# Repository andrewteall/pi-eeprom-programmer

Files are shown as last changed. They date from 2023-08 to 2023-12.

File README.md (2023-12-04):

# __A Raspberry Pi GPIO EEPROM Writer and Reader__ 

A way to write Parallel and Serial EEPROMs using the Raspberry Pi GPIO pins.

## __Quick Start__

### __Building the Circuit__
Before reading or writing any EEPROM you have to build the apprpriate circuit to do so.

You'll need a breadboard, jumper wires, and a 40-pin connector and cable to attach to the GPIO pins of the Raspberry Pi and a way to connect the opposite end to the breadboard. I like using one of the many Raspberry Pi GPIO Breakout boards available.

__Serial I2C EEPROM Circuit__
```
            Raspberry Pi GPIO                         I2C DIP8 Serial EEPROM
            3V3  (1) (2)  5V                   GND <-  A0 | (1) (8) | VCC -> 3V3
 SDA 5 -> GPIO2  (3) (4)  5V                   GND <-  A1 | (2) (7) | WP  -> GPIO16 (36)
 SCL 6 -> GPIO3  (5) (6)  GND                  GND <-  A2 | (3) (6) | SCL -> GPIO2  (3)
          GPIO4  (7) (8)  GPIO14               GND <- GND | (4) (5) | SDA -> GPIO3  (5)
            GND  (9) (10) GPIO15
         GPIO17 (11) (12) GPIO18
         GPIO27 (13) (14) GND   
         GPIO22 (15) (16) GPIO23
            3V3 (17) (18) GPIO24
         GPIO10 (19) (20) GND   
          GPIO9 (21) (22) GPIO25
         GPIO11 (23) (24) GPIO8 
            GND (25) (26) GPIO7 
          GPIO0 (27) (28) GPIO1 
          GPIO5 (29) (30) GND   
          GPIO6 (31) (32) GPIO12
         GPIO13 (33) (34) GND   
         GPIO19 (35) (36) GPIO16 -> 7 WP
         GPIO26 (37) (38) GPIO20
            GND (39) (40) GPIO21
   ```

   __Parallel EEPROM Circuit__
```
 IC  |   Raspberry Pi GPIO      | IC  |        Pi  |  DIP28 Parallel EEPROM  |  Pi         | DIP24 Parallel EEPROM
          3V3  (1) (2)  5V            |  (7)  GPIO4 <-  A14  (1) (28) VCC  -> 5V           |
I/O3 -> GPIO2  (3) (4)  5V            | (11) GPIO17 <-  A12  (2) (27) /WE  -> GPIO14 (8)   |
I/O4 -> GPIO3  (5) (6)  GND           | (13) GPIO27 <-   A7  (3) (26) A13  -> GPIO15 (10)  | VCC -> 5V
A14 ->  GPIO4  (7) (8)  GPIO14 -> /WE | (15) GPIO22 <-   A6  (4) (25) A8   -> GPIO18 (12)  | 
          GND  (9) (10) GPIO15 -> A13 | (19) GPIO10 <-   A5  (5) (24) A9   -> GPIO23 (16)  | 
A12 -> GPIO17 (11) (12) GPIO18 -> A8  | (21)  GPIO9 <-   A4  (6) (23) A11  -> GPIO24 (18)  | /WE -> GPIO14 (8)
 A7 -> GPIO27 (13) (14) GND           | (23) GPIO11 <-   A3  (7) (22) /OE  -> GPIO25 (22)  | 
 A6 -> GPIO22 (15) (16) GPIO23 -> A9  | (27)  GPIO0 <-   A2  (8) (21) A10  -> GPIO8  (24)  | 
          3V3 (17) (18) GPIO24 -> A11 | (29)  GPIO5 <-   A1  (9) (20) /CE  -> GPIO7  (26)  | 
 A5 -> GPIO10 (19) (20) GND           | (31)  GPIO6 <-   A0 (10) (19) I/O7 -> GPIO1  (28)  | 
 A4 ->  GPIO9 (21) (22) GPIO25 -> /OE | (33) GPIO13 <- I/O0 (11) (18) I/O6 -> GPIO12 (32)  | 
 A3 -> GPIO11 (23) (24) GPIO8  -> A10 | (35) GPIO19 <- I/O1 (12) (17) I/O5 -> GPIO16 (36)  | 
          GND (25) (26) GPIO7  -> /CE | (37) GPIO26 <- I/O2 (13) (16) I/O4 -> GPIO3  (38)  | 
 A2 ->  GPIO0 (27) (28) GPIO1  -> I/O7|          GND <- GND (14) (15) I/O3 -> GPIO2  (40)  | 
 A1 ->  GPIO5 (29) (30) GND           |
 A0 ->  GPIO6 (31) (32) GPIO12 -> I/O6| 
I/O0 ->GPIO13 (33) (34) GND           |
I/O1 ->GPIO19 (35) (36) GPIO16 -> I/O5| 
I/O2 ->GPIO26 (37) (38) GPIO20        | 
          GND (39) (40) GPIO21 ->     | 
   ```

   Alternatively a pcb can be ordered from any of the various manufacturers from the zipped gerbers contained in `hardware/manufacturing/pi-eeprom-programmer-v.v.v.zip`.

### __Installation and Raspberry Pi Setup__

If you plan to use serial EEPROMs you'll need to setup I2C on the Raspberry Pi. [Adafruit](https://learn.adafruit.com/adafruits-raspberry-pi-lesson-4-gpio-setup/configuring-i2c) has a great tutorial. Typically, if you're just using parallel EEPROM's then you can proceed to the next step. However, if the `libgpiod2` and `libgpiod-dev` packages are not installed on your Raspberry Pi you will need to to install them.

Download and compile the programmer software
```
git clone git@github.com:andrewteall/pi-eeprom-programmer.git
cd pi-eeprom-programmer/software
make
```

Install piepro

```
make install
```

That's it. You should be able to start reading and writing EEPROMs.

### __Installing the IC__
If you've recreated the circuit exactly from above or are using the pcb the IC should be installed so that the bottom left pin of the IC is aligned to the bottom left of the circuit.

### __Reading from an EEPROM__

To read an EEPROM, after building the circuit and inserting the IC, run the command
```sh
piepro -d -m EEPROM_MODEL
```
Where EEPROM_MODEL is typically the IC's part number such as at28c64, xl2816, at24c02, etc... This will dump the EEPROM's contents to standard out in a pretty format. If you wish to start or limit the addresses dumped you may specify the `-s ADDRESS` or `-l ADDRESS` flags respectively.

### __Writing to an EEPROM__

To write to an EEPROM, after building the circuit and inserting the IC, run the command
```sh
piepro -w file.bin -m EEPROM_MODEL
```
To compare you EEPROM to the file after writing, run the command

```sh
piepro -c file.bin -m EEPROM_MODEL
```
Where EEPROM_MODEL is typically the IC's part number such as at28c64, xl2816, at24c02, etc...

#### __A Quick Note About EEPROM Voltages__
Most modern EERPOMs will work but if you're using an obscure EEPROM you need to makes sure it can operate on 5v Vcc and 3.3v levels if it's a parallel EEPROM and 3.3v Vcc and 3.3v levels if it's a serial EEPROM.

## __Command Line Options__
```
Usage: piepro [options]
Options:
 -c FILE,   --compare FILE  Compare FILE and EEPROM and print number of differences.
            --chipname      Specify the chipname to use. Default: gpiochip0
 -d [N],    --dump [N]      Dump the contents of the EEPROM, 
                            0=PRETTY_WITH_ASCII, 1=BINARY, 2=TEXT, 3=LABELED, 4=PRETTY. Default: PRETTY_WITH_ASCII
 -e [N],    --erase [N]     Erase eeprom with specified byte. Default: 0xFF
 -f,        --force         Force writing of every byte instead of checking for existing value first.
 -id,       --i2c-device-id The address id of the I2C device.
 -h,        --help          Print this message and exit.
 -l N,      --limit N       Specify the maximum address to operate.
 -m MODEL,  --model MODEL   Specify EERPOM device model. Default: AT28C16.
            --no-validate-write 
                            Do not perform a read directly after writing to verify the data was written.
 -r [N],    --read [N]      Read the contents of the EEPROM, 
                            0=PRETTY_WITH_ASCII, 1=BINARY, 2=TEXT, 3=LABELED, 4=PRETTY. Default: PRETTY_WITH_ASCII
 -rb N,     --read-byte ADDRESS 
                            Read From specified ADDRESS.
 -q [N],     --quick [N]    Operates on N bytes at once for reads. Page Size if unspecified or writes. 
                            Implied --force and --no-validate-write.
 -s N,      --start N       Specify the minimum address to operate.
 -t,        --text          Interpret file as a text. Default: binary
                            Text File format:
                            [00000000]00000000 00000000
 -v N,      --v[vvvv]       Set the log verbosity to N, 0=OFF, 1=FATAL, 2=ERROR, 3=WARNING, 4=INFO, 5=DEBUG 6=TRACE. Default: WARNING
            --version       Print the piepro version and exit.
 -w FILE,   --write FILE    Write EEPROM with specified file.
 -wb ADDRESS DATA, --write-byte ADDRESS DATA 
                            Write specified DATA to ADDRESS.
 -wd [N],   --write-delay N Enable write delay. N Number of microseconds to delay between writes.
 -y,        --yes           Automatically answer Yes to write or erase EEPROM.

 Supported and tested Models:
        Note that the program may work if your EEPROM uses a similar pinout and
        voltages to the ones listed.
 Model       Size(B)  Addr Len  Data Len   Write Cycle(uS)  Page Size(B) Address Size(B)
----------------------------------------------------------------------------------------
xl2816        2048       11         8          10000            16             0
xl28c16       2048       11         8          10000            16             0
at28c16       2048       11         8           5000            16             0
at28c64       8192       13         8          10000            16             0
at28c256     32768       15         8           1000            64             0
at24c01        128        7         8           5000             8             1
at24c02        256        8         8           5000             8             1
at24c04        512        9         8           5000            16             2
at24c08       1024       10         8           5000            16             2
at24c16       2048       11         8           5000            16             2
at24c32       4096       12         8           5000            32             2
at24c64       8192       13         8           5000            32             2
at24c128     16384       14         8           5000            64             2
at24c256     32768       15         8           5000            64             2
at24c512     65536       16         8           5000           128             2
 ```

 ## __Features, Bugs, and Contributing__
If there's anything you'd like to add or find a bug please open an [issue](https://github.com/andrewteall/pi-eeprom-programmer/issues). If you'd like to implement those chages yourself please feel free to open a PR or fork the repository and make it your own.

## __License__
This repository is licensed under the [MIT-0 License](LICENSE) for everything not contained in the hardware folder and it's sub folders. For all files and folders in the hardware folder and it's sub folders, they are licensed under [CC0](https://creativecommons.org/publicdomain/zero/1.0/). You are free to use, modify, and distribute the project according to the terms of these licenses.

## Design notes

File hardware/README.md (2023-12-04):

# __A Raspberry Pi GPIO EEPROM Writer and Reader__ 

A way to write Parallel and Serial EEPROMs using the Raspberry Pi GPIO pins.

## __Introduction__
The Raspberry Pi EEPROM Programmer is a hardware project that facilitates the programming and updating of EEPROMs using a Raspberry Pi. Instead of having to wire a circuit up on a bread board, the idea is just to be able to plug the EEPROM in to the pcb via a socket of some sort and then plug the pcb into the Raspberry Pi's GPIO pins.

This README provides an overview of the features, hardware design, and usage instructions for the Raspberry Pi EEPROM Programmer.

## __Folder Structure__

### Hardware Design
The hardware design files for the Raspberry Pi EEPROM Programmer can be found in the [hardware](../hardware/design/) directory of this repository. The design includes:

- **Kicad Project File:** The Kicad 6 project file to open the designs.
- **Schematic:** The schematic diagram detailing the connections between components and the Raspberry Pi.
- **PCB Layout:** The PCB layout design files used for creating the physical printed circuit board.

The hardware design is created using industry-standard design software, and you are encouraged to review, modify, or contribute to the design according to your needs.

### Manufacturing
The manufacturing files for the Raspberry Pi EEPROM Programmer can be found in the [manufacturing](../hardware/manufacturing/) directory of this repository.

- **Bill of Materials:** A list of all components required for building the programmer.
- **Gerbers:** Ready to build design files for the programmer.

### Repository Related Files

- **.README.md:** Resource on how to build, use, and design this hardware.
- **.gitignore:** Hardware specific gitignore for this repository.

## __Design Updates to the Hardware/Contributing__
Starting with version 1.0.0 I have tried not to have any breaking changes which should be very easy given such simple hardware. 
If you want to contribute and make any changes to this repo please ensure that you don't break any backwards compatibility to the hardware unless you plan on forking it and making it your own. When making non-breaking minor changes to the design please use a branch with the next minor version(1.+.0) or next patch version(1.x.+) and update the schematic and pcb accordingly.

## __Building the Hardware in Kicad__
When generating the appropriate gerber and drill files they should go in the [gerbers](./manufacturing/gerbers/) folder. Any new version should provide a zipped file in [manufacturing](./manufacturing/) folder containing all the build files and replacing the old version. 
```
zip -j manufacturing/pi-eeprom-programmer-$(git rev-parse --abbrev-ref HEAD).zip manufacturing/gerbers/*
```
This should make it easy to upload the design to the pcb manufacturers. The defaults in Kicad should befine to generate gerbers and drill files only the output directory should have to be changed.

## __BOM__
| ID | Designator | Package | Quantity | Designation | Part Number/Link |
|:--:|:---:|---|:---:|---|:---:|
| 1  | J1 | PinSocket_2x20_P2.54mm_Horizontal  | 1 | Raspberry Pi GPIO Connector |  [SFH11-PBPC-D20-RA-BK](https://www.digikey.com/en/products/detail/sullins-connector-solutions/SFH11-PBPC-D20-RA-BK/1990101)  |
| 2  | U1 | DIP-28_W15.24mm_Socket | 1 | ZIF Socket |  [28-6554-11](https://www.digikey.com/en/products/detail/aries-electronics/28-6554-11/27594) |
| 3  | U2 | DIP-8_W7.62mm_Socket | 1 | | |
| 4  | J2 | PinHeader_1x03_P2.54mm_Vertical | 1 | Conn_01x03 |  [TS-103-G-A](https://www.digikey.com/en/products/detail/samtec-inc/TS-103-G-A/1105459) |
| 5  | * | Conn_Jumper_Shorting | 1 | * |  [QPC02SXGN-RC](https://www.digikey.com/en/products/detail/sullins-connector-solutions/QPC02SXGN-RC/2618262) |

\* The Jumper Shunt is not listed anywhere in the schematic

__Notes:__
* U2 is not required unless you are not using the ZIF Socket or 28-Pin IC Socket in which case an 8-Pin IC Socket may be used.
* Similarly U1 may be substituted for a less expensive 28-Pin IC Socket.
* In certain cases if the ZIF socket is not used both the 28-Pin Socket and 8-Pin Socket may be used at the same time.
* All the parts can be found on via other sources so feel free to find them where they are the cheapest.

## __Assembling the PCB__
There are a very low number of components on the board and assembly is straight forward. One of the biggest options you have is the type of socket used. The BOM includes a Universal ZIF Socket(U1) that allows for plugging in both narrow and wide ICs, however a standard 28-Pin Wide DIP Socket(U1) can be used if you only need to program wide chips or an 8-Pin DIP Socket(U2) can be used for small serial EEPROMs. You can use either or, with a little encouragement, have both sockets in place at the same time. This is much cheaper than using the ZIF sockets but not as elegant(or as good for the IC Pins). 

J2 is a 1x3 Pin Header meant to be used with a shunt jumper to select between the different types of EEPROMs, 24-Pin or 28-Pin Parallel EEPROMS or 8 Pin Serial EEPROMs. You can also install a small SPDT sliding switch in place of the Pin Headers and the serial programming will work in either position.

J1 should be right angle 40-Pin connector. If you use a standard vertical 40-Pin Connector it will orient the EEPROM Programmer vertical/perpendicular to a Pi 400 and parallel and updside down to a standard Pi 4.

While I've included sources for all the parts feel free to use your own or source them from wherever you like or can find them cheapest. I've used a number of combinations of different components in testing and they've all worked fine.

Start by install the Sockets(U1/U2)(smallest first if you are trying to use both). Then install the Pin Header(JP2) and add your jumper shunt. Finally, install the right angle 40-Pin Connector.

## __Installation/Usage__
The Pi EEPROM Programmer should plug right into the GPIO Pins of the Raspberry Pi 4 or 400. Take note to make sure the pins are aligned correctly if you opt not to use a keyed 40-Pin connector.

For the Pi 400 the Programmer should stick out of the back of the case and for a Pi 4 the programmer should be vertical straight up assuming you are using the standard components and not others mentioned above.

You can then use the software provided in this repositor to read and write EEPROMs.

## __EEPROM Voltages__
See [A Quick Note About EEPROM Voltages](../README.md#a-quick-note-about-eeprom-voltages)

## __Features, Bugs, and Contributing__
If there's anything you'd like to add or find a bug please open an [issue](https://github.com/andrewteall/pi-eeprom-programmer/issues). If you'd like to implement those chages yourself please feel free to open a PR or fork the repository and make it your own.

## __License__
This hardware project is licensed under the [CC0](LICENSE). You are free to use, modify, and distribute the project according to the terms of the license.

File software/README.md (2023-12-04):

# __A Raspberry Pi GPIO EEPROM Writer and Reader__ 

A way to write Parallel and Serial EEPROMs using the Raspberry Pi GPIO pins.

This repository contains the software component for the Raspberry Pi EEPROM Programmer. The software is designed to work in conjunction with the hardware components to enable programming and updating of EEPROMs (Electrically Erasable Programmable Read-Only Memory) using a Raspberry Pi or the software can be used with a breadboard with the appropriate circuit wired up.

## __Introduction__

The Raspberry Pi EEPROM Programmer software provides a user-friendly interface to interact with the hardware and perform programming tasks on EEPROM chips.

This README provides an overview of the features, installation instructions, and usage guidelines for the Raspberry Pi EEPROM Programmer software.

## __Building__
See [Quick Start](../README.md#quick-start)

## __Installation__
See [Quick Start](../README.md#quick-start)

## __Flags and Options__
See [Flags](../README.md#command-line-options)

## __Quirks__
--no-validate-write has no affect on I2C devices.

## __Updating__
Updates can be performed by just running
```sh
make install
```
and the new version will be installed over the existing verison. 

## __Uninstall__
To uninstall just run 
```sh
make uninstall
```
from your source code directory.

## __Features, Bugs, and Contributing__
If there's anything you'd like to add or find a bug please open an [issue](https://github.com/andrewteall/pi-eeprom-programmer/issues). If you'd like to implement those chages yourself please feel free to open a PR or fork the repository and make it your own.

## __License__
This software project is licensed under the [MIT-0 License](LICENSE). You are free to use, modify, and distribute the project according to the terms of the license.

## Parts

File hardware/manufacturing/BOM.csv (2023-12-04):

Id | Designator | Package | Quantity | Designation | Supplier and ref
1 | J1 | PinSocket_2x20_P2.54mm_Horizontal | 1 | Raspberry Pi GPIO Connector
2 | U1 | DIP-28_W15.24mm_Socket | 1 | ZIF Socket
3 | U2 | DIP-8_W7.62mm_Socket | 1 | 24C01-24C1024
4 | J2 | PinHeader_1x03_P2.54mm_Vertical | 1 | Conn_01x03

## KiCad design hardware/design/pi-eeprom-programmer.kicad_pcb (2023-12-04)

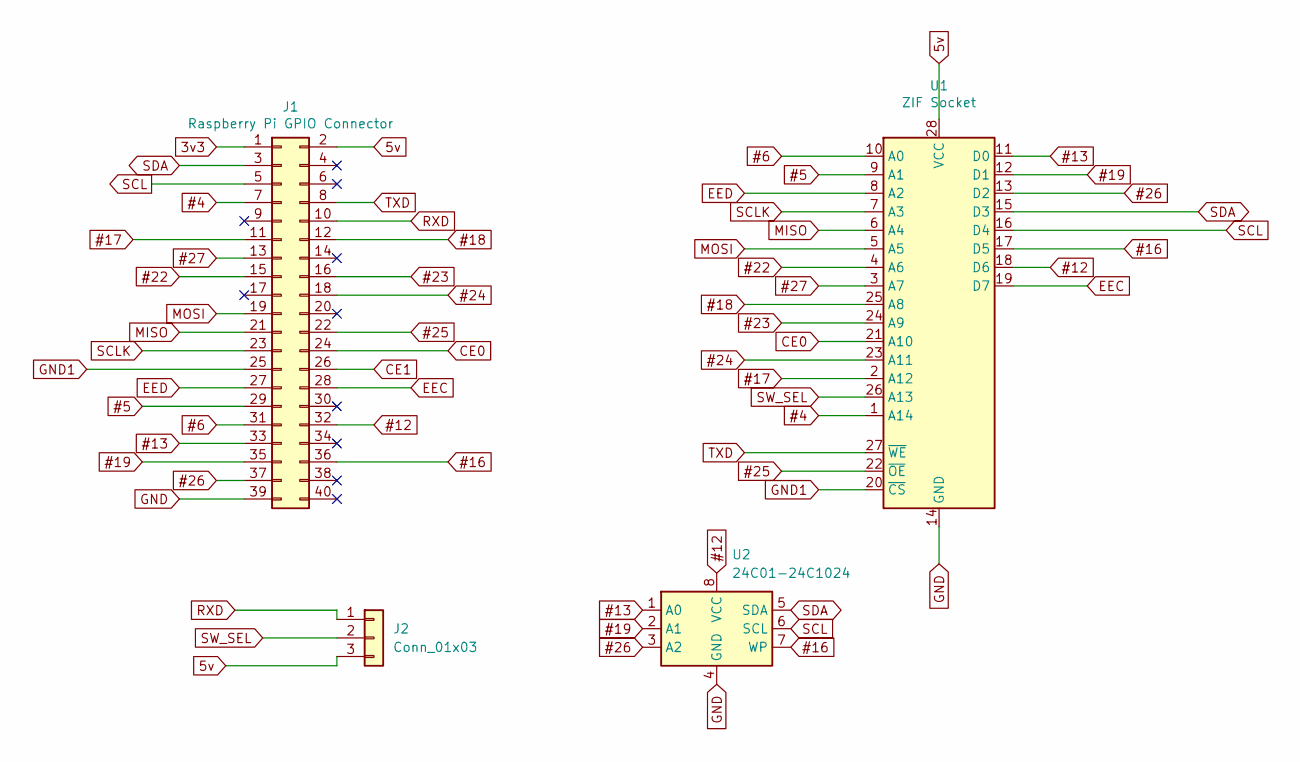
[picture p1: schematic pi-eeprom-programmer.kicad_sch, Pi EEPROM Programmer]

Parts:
J1: Raspberry Pi GPIO Connector; PinSocket_2x20_P2.54mm_Horizontal
J2: Conn_01x03; PinHeader_1x03_P2.54mm_Vertical
U1: ZIF Socket; DIP-28_W15.24mm_Socket
U2: 24C01-24C1024; DIP-8_W7.62mm_Socket

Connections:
3v3: J1.1
5v: J1.2, J2.3, U1.28 (VCC)
#4: J1.7, U1.1 (A14)
#5: J1.29, U1.9 (A1)
#6: J1.31, U1.10 (A0)
#12: J1.32, U1.18 (D6), U2.8 (VCC)
#13: J1.33, U1.11 (D0), U2.1 (A0)
#16: J1.36, U1.17 (D5), U2.7 (WP)
#17: J1.11, U1.2 (A12)
#18: J1.12, U1.25 (A8)
#19: J1.35, U1.12 (D1), U2.2 (A1)
#22: J1.15, U1.4 (A6)
#23: J1.16, U1.24 (A9)
#24: J1.18, U1.23 (A11)
#25: J1.22, U1.22 (~OE)
#26: J1.37, U1.13 (D2), U2.3 (A2)
#27: J1.13, U1.3 (A7)
CE0: J1.24, U1.21 (A10)
CE1: J1.26
EEC: J1.28, U1.19 (D7)
EED: J1.27, U1.8 (A2)
GND: J1.39, U1.14 (GND), U2.4 (GND)
GND1: J1.25, U1.20 (~CS)
MISO: J1.21, U1.6 (A4)
MOSI: J1.19, U1.5 (A5)
RXD: J1.10, J2.1
SCL: J1.5, U1.16 (D4), U2.6 (SCL)
SCLK: J1.23, U1.7 (A3)
SDA: J1.3, U1.15 (D3), U2.5 (SDA)
SW_SEL: J2.2, U1.26 (A13)
TXD: J1.8, U1.27 (~WE)

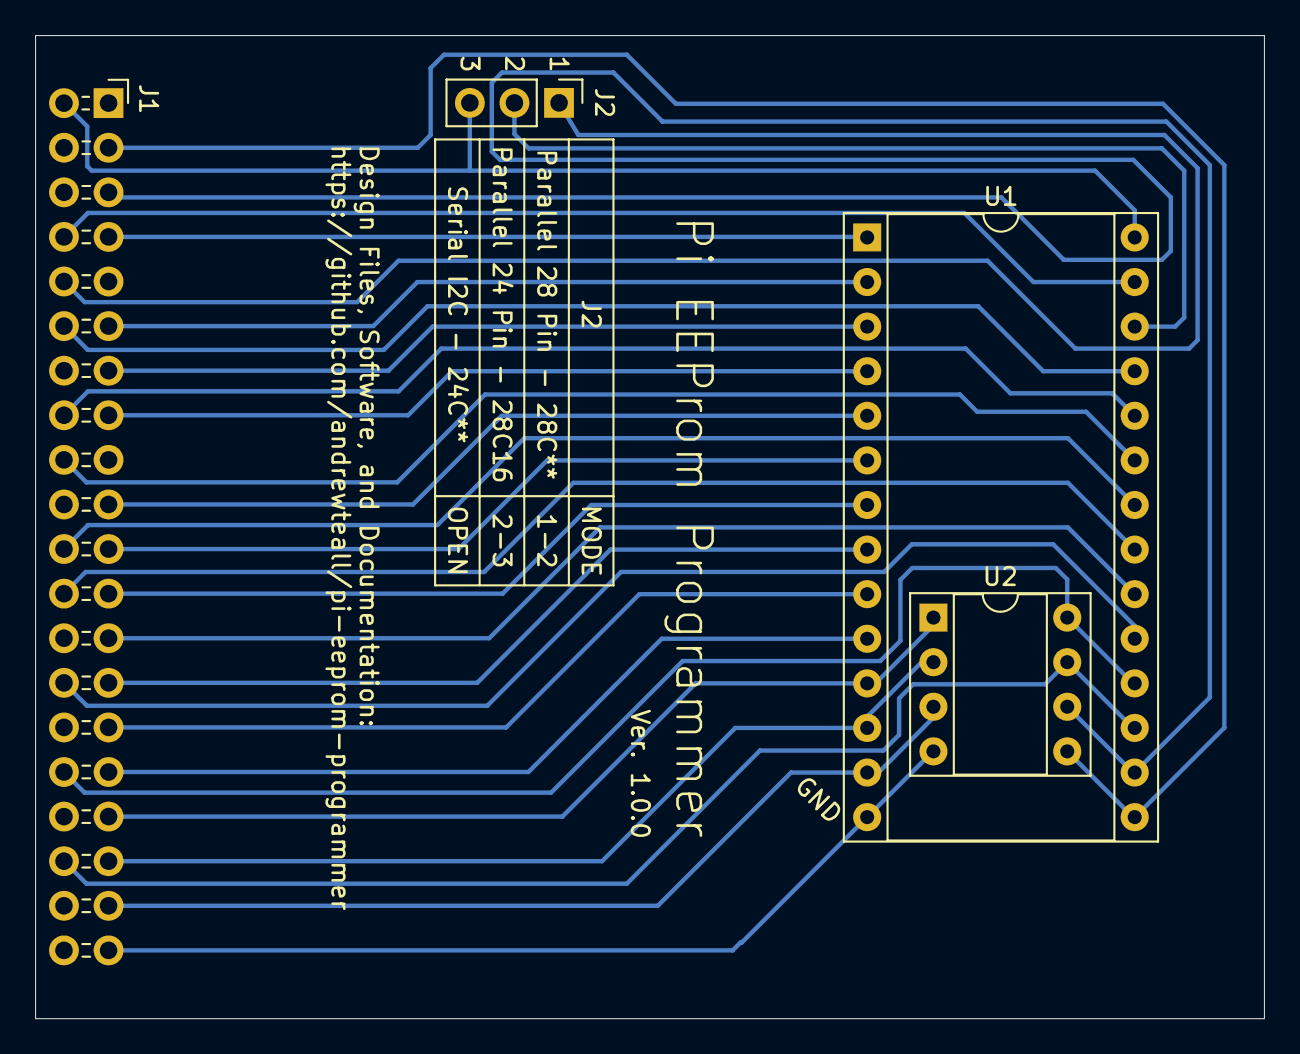
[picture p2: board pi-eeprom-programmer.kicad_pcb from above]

Board: 2 copper layers, 70.0 x 56.0 mm, 4 parts (0 on the bottom side), 29 nets.

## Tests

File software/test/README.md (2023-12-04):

## __Testing__

### __Quick Start__
Plug the device to be used for testing into the GPIO Pins.

To run parallel EEPROM tests:
```sh
make EEPROM_MODEL={EEPROM_MODEL} test
```

To run I2C EEPROM tests:
```sh
make EEPROM_MODEL={EEPROM_MODEL} test_I2C
```

Where {EEPROM_MODEL} is the model of EEPROM you want to test(without brackets).

### __Running Tests__

To just build the test runner:
```sh
make test_runner_piepro
```

From there the test suit can be run with:

```sh
./bin/test_runner_piepro -m EEPROM_MODEL
```
Where EEPROM_MODEL is the model of EEPROM you want to test.

By default all Unit and Functional tests are run. You can limit which set is run with the `-u` or `--unit` flag to only runs Unit Tests or the `-f` or `--functional` flag to only runs Functional Tests.

Test data is required to run the tests and can automatically be generated with the `-g` or `--generate` flag. To only generate the test data and then exit the `-go` or `--generate-only` flag may be set.

By default Parallel EEPROM tests are run. To run the I2C tests use the `-I2C` flag.

All suites and tests are run when the test runner is invoked with out the `-s N` or `--suite N` flag which will specify to only run `N` suite. The same goes for `-t N` or `--test N` flag which will only run the specified `N` test.

The final flag, `-l N` or `--limit N`, will artificially limit the size of the EEPROM to size `N`. This is useful for quickly testing a certain test on large EEPROMS.

### __Writing Tests__

The included UTest framework should be used to write tests. Suites and tests may be added in the appropriate functions with the supplied functions in `uTest.h`.

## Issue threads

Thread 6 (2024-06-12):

5V to GPIO while reading

HollayHorvath, 2024-06-12:
I just stumbled upon your project while I was planning to build my own EEPROM programmer, excellent project, thank you for it!

However I have a question about the read mode. The 28C256 outputs the Vcc on the data pins while being read which is +5V however the Raspberry Pi GPIO pins are only capable to handle +3.3V. Based on the documentation the 5V can damage the pins or could kill the whole device. Did you experience any issues with it?

What I found on some forums that 5V with some low uA current should be fine, however there was no consensus on what the exact number would be. Do you have some numbers around this possible problem?

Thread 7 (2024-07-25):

Suggestions for improving the README

danboid, 2024-07-25:
Hi Andrew

Thanks for writing pi-eeprom-programmer, it sounds like it should be very useful, if I understood how to wire it up!

There are two problems with the README, the first is minor and easily fixed. The first line of the installation instructions is:

```
git clone git@github.com:andrewteall/pi-eeprom-programmer.git
```

I'm pretty sure that command will only work for you as the owner of the repo so that line should be changed to:

```
git clone https://github.com/andrewteall/pi-eeprom-programmer.git
```

Which will work for everyone with git and an internet connection.

My main problem is that I cannot make any sense of the circuit info. The circuit info would be much better presented in markdown table format to make it easier to read:

https://www.codecademy.com/resources/docs/markdown/tables

More importantly, what do they mean? I presume:

I/O3 -> GPIO2  (3)

Means that I'll need to find the datasheet for my EEPROM to find which pin on my EEPROM is I/O3 then connect that to GPIO2, which is GPIO pin 3 right? Because you have notated it like this I can only presume that the pinout for every 28 pin EEPROM is different which is why you don't tell us which pins on the IC connect to specific GPIO pins? I think you should at least explain this and maybe also link to the datasheets for some popular EEPROMS too maybe?

In my case I have some Winbond W27C512 EEPOMS that I want to flash the Atari TOS roms onto. I presume I should be able to do that OK with your program?

Thanks for your help!

danboid, 2024-07-25:
I've failed at the first hurdle.

I've got an RPi4 so its a 40 pin GPIO header.

I'm looking at the pin configuration diagram on p3 of:

https://mm.digikey.com/Volume0/opasdata/d220001/medias/docus/900/W27C512.pdf

I think the README says I need to connect pin I/O3 on the IC to GPIO2  (pin 3 on the GPIO header) but I don't see any mention of I/O3 on the W27C512 pin configuration diagram.

Does this mean I cannot program the W27C512 using your program?

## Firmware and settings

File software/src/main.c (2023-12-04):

#include <stdio.h>

#include "piepro.h"

int main(int argc, char *argv[]){	
    int error = 0;
	
    if (argc == 1){
		printHelp();
		error = -1;
	} else {
        /*********************************************************************/
        /************************* Init Program ******************************/
        struct EEPROM eeprom;
        struct GPIO_CONFIG gpioConfig;
        struct OPTIONS options;
		
        if(parseCommandLineOptions(&options, argc, argv)){
            fprintf(stderr,"Error parsing command line options\n");
            return -1;
        }
        
        if(initHardware(&options, &eeprom, &gpioConfig)){
            fprintf(stderr,"Error initializing hardware\n");
            return -1;
        }
        
        /*********************************************************************/
        /************************* Program  Start ****************************/
        switch(options.action){
            case WRITE_FILE_TO_ROM:
            case COMPARE_FILE_TO_ROM:
            {
                // open file to read
                FILE* romFile = fopen(options.filename, "r");
                if(romFile == NULL){
                    fprintf(stderr,"Error Opening File\n");
                    error = -1;
                    break;
                }
                if(options.action == WRITE_FILE_TO_ROM){
                    char confirmation = 'n';
                    if(options.promptUser){
                        printf("Are you sure you want to write to the EEPROM? y/N\n");
                        confirmation = getchar();  
                    }    
                    if(confirmation == 'y' || confirmation == 'Y' || !options.promptUser){
                        error = writeFileToEEPROM(&gpioConfig, &eeprom, romFile);
                        fprintf(stdout,"Wrote %i bytes\n", eeprom.byteWriteCounter);
                    } else {
                        printf("Aborting write operation.\n");
                        break;
                    }

                } else {
                    int bytesNotMatched = compareFileToEEPROM(&gpioConfig, &eeprom, romFile);
                    if(bytesNotMatched == 0) {
                        fprintf(stdout,"All bytes match\n");
                    } else if(bytesNotMatched == -1){
                        fprintf(stdout,"Error comparing file.\n");
                        error = -1;
                    } else {
                        error = -1;
                        fprintf(stderr,"%i bytes do not match\n", bytesNotMatched);
                    }
                }
                fclose(romFile);   
                break;
            }
            case DUMP_ROM:
                error = printEEPROMContents(&gpioConfig, &eeprom, options.dumpFormat);
                break;
            case ERASE_ROM:
            {
                char confirmation = 'n';
                if(options.promptUser){
                    printf("Are you sure you want to erase the EEPROM? y/N\n");
                    confirmation = getchar();  
                }
                if(confirmation == 'y' || confirmation == 'Y' || !options.promptUser){
                    error = eraseEEPROM(&gpioConfig, &eeprom, options.eraseByte);
                } else {
                    printf("Aborting erase operation.\n");
                    break;
                }

                if(error == 0) {
                    fprintf(stdout,"Sucessfully Erased %i bytes in EEPROM with 0x%02x\n", \
                                                                eeprom.byteWriteCounter, options.eraseByte);
                } else {
                    error = -1;
                    fprintf(stdout,"Unable to completely erase EEPROM with 0x%02x\n", options.eraseByte);
                }
                break;
            }
            case WRITE_SINGLE_BYTE_TO_ROM:
                error = writeByteToAddress(&gpioConfig, &eeprom, options.addressParam, options.dataParam);
                if(!error){
                    fprintf(stdout,"Wrote Byte: 0x%02x to Address: 0x%02x\n", options.dataParam, options.addressParam);
                } else {
                    fprintf(stderr,"Error writing Byte: 0x%02x to Address: 0x%02x\n",options.dataParam,options.addressParam);
                }
                break;
            case READ_SINGLE_BYTE_FROM_ROM:
            {
                int readVal = readByteFromAddress(&gpioConfig, &eeprom, options.addressParam);
                if(readVal != -1){
                    fprintf(stdout,"0x%02x\n", readVal);
                } else {
                    error = readVal;
                }
                break;
            }
            case NOTHING:
		        fprintf(stdout,"No action specified. Run piepro -h for a list of options\n");
                break;
        }

        /*********************************************************************/
        /************************ Program Cleanup ****************************/
        cleanupHardware(&gpioConfig, &eeprom);

    }

	return error;
}

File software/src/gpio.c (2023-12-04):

#include <fcntl.h>
#include <gpiod.h>
#include <linux/i2c-dev.h>
#include <sys/ioctl.h>
#include <sys/mman.h>
#include <unistd.h>

#include "gpio.h"
#include "utils.h"
#include "ulog.h"

#define MAX_USABLE_GPIO_LINES 34
#define SDA1_PIN 2
#define SCL1_PIN 3
#define BLOCK_SIZE 4096

enum ALT_MODE {ALT0=0,ALT1,ALT2,ALT3,ALT4,ALT5};

// GPIO setup macros. Always use INP_GPIO(x) before using OUT_GPIO(x) or SET_GPIO_ALT(x,y)
#define INP_GPIO(gpio,g) *(gpio+((g)/10)) &= ~(7<<(((g)%10)*3))
#define SET_GPIO_ALT(gpio,g,a) *(gpio+(((g)/10))) |= (((a)<=3?(a)+4:(a)==4?3:2)<<(((g)%10)*3))

/* Set the ALT MODE of the specified pin */
void setPinAltModeGPIO(volatile unsigned int* gpio, int pin, enum ALT_MODE altMode){
    INP_GPIO(gpio,pin);
    SET_GPIO_ALT(gpio,pin,altMode);
}

/* Ensure chip and line number are valid */
int checkConfigGPIO(struct GPIO_CHIP* gpioChip, int gpioLineNumber){
    int rtnVal = 0;

    if(gpioChip == NULL){
        ulog(ERROR,"gpioChip cannot be NULL.");
        return -1;
    }
    if (gpioChip != NULL && gpioChip->isSetup != 1){
        ulog(ERROR,"GPIO is not setup.");
        return -1;
    }
    if( gpioLineNumber < 0 || gpioLineNumber >= gpioChip->numLinesInUse){
        ulog(ERROR,"Pin Number: %i is out of range of configured Pins",gpioLineNumber);
        return -1;
    }
    return rtnVal;
}

/* Sets up GPIO to be used */
int setupGPIO(struct GPIO_CHIP* gpioChip){
    int err = 0;
    
    if(gpioChip == NULL){
        ulog(ERROR,"gpioChip cannot be NULL");
        return -1;
    }
    if(gpioChip->chipname == NULL){
        ulog(ERROR,"Chipname cannot be NULL");
        return -1;
    }
    if(gpioChip->consumer == NULL){
        ulog(ERROR,"Consumer cannot be NULL");
        return -1;
    }
    if(gpioChip->isSetup){
        ulog(ERROR,"GPIO is already setup");
        return -1;
    }
    
    gpioChip->chip = gpiod_chip_open_by_name(gpioChip->chipname);
    if (gpioChip->chip == NULL){
        ulog(ERROR,"Unable to get chip by name: %s",gpioChip->chipname);
        return -1;
    }
    if(gpioChip->numGPIOLines > MAX_USABLE_GPIO_LINES && gpioChip->numGPIOLines < gpiod_chip_num_lines(gpioChip->chip)){
        ulog(ERROR,"Invalid Line Count Requested for Chip. Max for Chip: %i",MAX_USABLE_GPIO_LINES);
        return -1;
    }
    if(gpioChip->numGPIOLines >= gpiod_chip_num_lines(gpioChip->chip) || gpioChip->numGPIOLines < 0){
        ulog(ERROR,"Invalid Number of Lines Requested for Chip. Max: %i",gpiod_chip_num_lines(gpioChip->chip));
        return -1;
    }

    for(int i=0; i < gpioChip->numGPIOLines && err == 0; i++){
        gpioChip->gpioLines[i] = gpiod_chip_get_line(gpioChip->chip, i);
        if(gpioChip->gpioLines[i] == NULL){
            ulog(ERROR,"Unable to get line: %i",i);
            err = -1;
        } else {
            err = gpiod_line_request_output(gpioChip->gpioLines[i], gpioChip->consumer, 0);
            if(err){
                ulog(ERROR,"Error initially requesting line for OUTPUT");
            }
        }
    }
    if(err != -1){
        gpioChip->isSetup = 1;
        gpioChip->numLinesInUse = gpioChip->numGPIOLines;
    }
    
    return err;
}

/* Set the GPIO Pin mode to be INPUT or OUTPUT */
int setPinModeGPIO(struct GPIO_CHIP* gpioChip, int gpioLineNumber, int pinMode){
    int err = 0;
    
    if(checkConfigGPIO(gpioChip,gpioLineNumber)){
        return -1;
    }

    if(pinMode == OUTPUT){
        // output
        err = gpiod_line_set_config(gpioChip->gpioLines[gpioLineNumber],GPIOD_LINE_REQUEST_DIRECTION_OUTPUT,0,0);
        if(err){
            ulog(ERROR,"Error requesting OUTPUT");
        }
    } else if(pinMode == INPUT){
        // input
        err = gpiod_line_set_config(gpioChip->gpioLines[gpioLineNumber],GPIOD_LINE_REQUEST_DIRECTION_INPUT,0,0);
        if(err){
            ulog(ERROR,"Error requesting INPUT");
        }
    } else {
        ulog(ERROR,"Invalid Pin Mode: %i",pinMode);
        err = -1;
    }
    return err;
}

/* Read from a specified GPIO Pin */
int readGPIO(struct GPIO_CHIP* gpioChip, int gpioLineNumber){
    int val = 0;
 
    if(checkConfigGPIO(gpioChip,gpioLineNumber)){
        return -1;
    }

    if((gpiod_line_direction(gpioChip->gpioLines[gpioLineNumber]) == GPIOD_LINE_DIRECTION_INPUT)){
        val = gpiod_line_get_value(gpioChip->gpioLines[gpioLineNumber]);
        if( val == -1){
            ulog(ERROR,"Failed to read input on Pin %i",gpioLineNumber);
        }
    } else {
        val = -1;
        ulog(ERROR,"Pin: %i not configured as INPUT. Cannot be read.",gpioLineNumber);
    }
    return val;
}
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

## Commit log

2022-09-13 Handle device type -t --type
2022-09-13 Cleanup Header and fix type handling
    [piepro.c]
2022-09-14 Fix VCC Pin
2022-10-11 Fix pin configuration for different chips
    [piepro.c]
2022-10-12 More small fixes adjustments to write cycle time
    [piepro.c]
2022-10-12 Serial support, write cycle delay adjust, i2c id
2022-10-15 Support I2C IDs and WP
2023-08-09 First pass adding hardware
    [pi-eeprom-programmer-B_Cu.gbr, pi-eeprom-programmer-B_Mask.gbr, pi-eeprom-programmer-B_Paste.gbr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]
2023-08-10 *Broken* Restructured Software Project
    [main.c, piepro.c]
2023-08-16 Switch from WiringPi to Chardev GPIO
2023-08-16 Updated board to reuse GPIO 2 & 3 for Chardev switch
    [pi-eeprom-programmer-B_Cu.gbr, pi-eeprom-programmer-B_Mask.gbr, pi-eeprom-programmer-B_Paste.gbr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]
2023-08-20 Removed add kicad prl file from source control
2023-08-21 Added kicad prl file to .gitignore
2023-08-21 Updated PCB to include spot for Serial EEPROM and updated README to reflect it
    [pi-eeprom-programmer.kicad_pcb, pi-eeprom-programmer.kicad_sch]
2023-08-21 Added BOM and cleaned up schematic
    [BOM.csv, pi-eeprom-programmer.kicad_pcb, pi-eeprom-programmer.kicad_sch]
2023-08-21 Added voltage info to hardware README
2023-08-21 Update Hardware folder structure and generate zip
    [BOM.csv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]
2023-08-22 Fix README path to zipped gerbers
2023-08-23 Fixes from GPIO tests
    [gpio.c, piepro.c]
2023-08-24 Fix when no dump format is specified.
    [piepro.c]
2023-08-28 More gpio tests and fixes
    [gpio.c, piepro.c]
2023-09-11 Revamp to support multiple byte I2C addresses
2023-09-11 Switch #define to enum in gpio.c
2023-09-14 Fixed GPIO tests after refactor
    [gpio.c]
2023-11-07 Added I2C Dummy write
2023-11-07 Fix gpioLines never being NULL check
    [gpio.c]
2023-11-07 Fix write cycle time to be used is polling is disabled
    [piepro.c]
2023-11-07 Fix high value address off by 1 error
    [piepro.c]
2023-11-08 Handle parameter switch segfault when last argument
2023-11-08 Updated and corrected help docs
    [piepro.c]
2023-11-08 ULog Use fprintf instead of printf
2023-11-08 Fixed reading past end of file when smaller than EEPROM
    [piepro.c]
2023-11-09 Exit if I2C cannot be setup
2023-11-09 Move I2C setup to after pins are configured
2023-11-09 Fix multibyte I2C addresses and data sizings
    [gpio.c, piepro.c]
2023-11-09 List all supported devices and parameters
2023-11-09 Fix str2bin error messages printing when not supposed to
    [piepro.c]
2023-11-13 Fix writing and comparing text files
    [piepro.c]
2023-11-13 Switch logging to stderr
2023-11-13 Fix binary text export to be used with program
    [piepro.c]
2023-11-14 Fixed numBytesToRead in gpio for readI2C
    [gpio.c]
2023-11-16 Fixed parallel bulk write
    [piepro.c]
2023-11-16 Better error handling for main
    [main.c]
2023-11-16 Better log message when quick compare doesn't match
    [piepro.c]
2023-11-17 Added readChunk option. Fixed reading past end of file
    [piepro.c]
2023-11-17 Cleanup printEEPROM added return val and fixed printing
    [main.c, piepro.c]
2023-11-19 Fix EOF not detected
    [piepro.c]
2023-11-26 Fix begin var not error with clang
    [piepro.c]
2023-11-28 Fix quick write byte error
    [piepro.c]
2023-11-28 Add TRACE log level
2023-11-28 Fix Clang fgetc error with char
    [piepro.c]
2023-11-28 Fix Clang Case Statment errors
    [main.c]
2023-11-29 Fix Quick byte reads
    [piepro.c]
2023-11-29 Re-Fix Quick byte read
    [piepro.c]
2023-11-30 Fix text file writing and matching with negative number
    [piepro.c]
2023-12-01 Fix duplicate byte read increments
    [piepro.c]
2023-12-02 Fixed Not Quick reading num bytes
    [piepro.c]
2023-12-03 Added Pretty Print with ASCII option
2023-12-04 Track .zip files as binary in git
2023-12-04 Updated Version to 1.0.0 and generated new gerbers and zip
    [pi-eeprom-programmer-B_Cu.gbr, pi-eeprom-programmer-B_Mask.gbr, pi-eeprom-programmer-B_Paste.gbr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]
